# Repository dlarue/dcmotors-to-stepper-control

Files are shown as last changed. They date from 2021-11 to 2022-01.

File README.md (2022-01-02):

# dcmotors-to-stepper-control
This Arduino program is refered from: https://github.com/tuenhidiy/CNC-PLOTTER-FROM-DC-MOTORS-AND-OPTICAL-ENCODERS
Requires the L298N library by Andrea Lombardo found in the Arduino IDE Library Manager

It is used to control 2 DC motors having 2 optical encoders with step / direction signals typically found as stepper driver inputs on CNC machines.
In this project, DC motors can be simulated as same as stepper motors and we can control them via GRBL firmware for CNC application.
Combined with a GRBL based Arduino, a 3 axis CNC plotter/painter can be built from 2 DC motors w/encoders and a servo to operate as the Z axis.

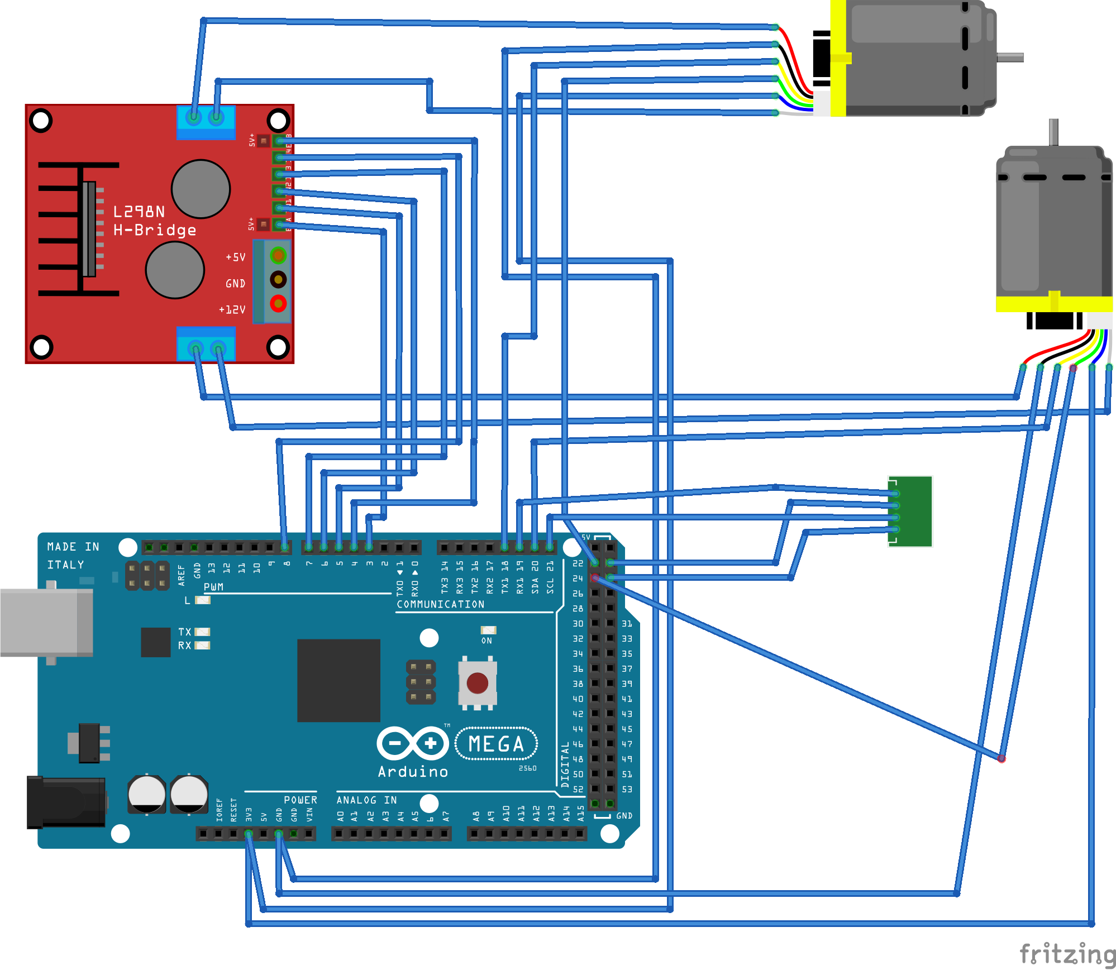
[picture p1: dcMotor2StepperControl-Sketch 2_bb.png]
Fritzing diagram


Inspired by this DIY wall painting bot with the hopes of having far more resolution capabilities and instead of using custom software for the workflow
be able to use commonly used CNC CAM software for GCode generation. 
https://niklasroy.com/graffomat/

Forked from this project in hopes it'll help other scale to bigger motors and higher accuracy:
https://www.instructables.com/3-AXIS-CNC-PLOTTER-FROM-DC-MOTORS-AND-OPTICAL-ENCO/

The firmware runs on an Arduino Mega 2560 as it uses 4 interrupts to handle step/direction input and encoder inputs.
The motors are driven by a L298N H-bridge contolling each channels via "ENA,IN1,IN2,IN3,IN4,ENB" inputs(outputs on the Arduino).
Motor encoder outputs are also connected directly to the Arduino Mega.

Arduino Pin	->	signal name

3		->	L298N-ENA

4		->	L298N-ENB

5		->	L298N-IN2

6		->	L298N-IN1

7		->	L298N-IN3

8		->	L298N-IN4

18		<-	MotorX-Encoder-chanA	(interrupt)

19		<-	MotorX-Step		(interrupt)

20		<-	MotorY-Encoder-chanA	(interrupt)

21		<-	MotorY-Step		(interrupt)

22		<-	MotorX-Encoder-chanB

23		<-	MotorX-Direction

24		<-	MotorY-Encoder-chanB

25		<-	MotorY-Direction

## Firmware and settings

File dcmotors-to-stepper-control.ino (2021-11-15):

/* 
 * This Arduino program is refered from: https://github.com/cswiger/dcservodrive by cswiger.
 * In this project, DC motors can be simulated as same as stepper motors and we can control them via GRBL firmware for CNC application.  
 */
   
// Timer2 library
#include "FlexiTimer2.h"

// PID library
#include <PID_v1.h>

// L298N library
// For two motors instance at once
#include <L298NX2.h>

// Quadrature Encoder Library
#include "Encoder.h"

// Pin definition
const unsigned int EN_A = 3;
const unsigned int IN1_A = 6;
const unsigned int IN2_A = 5;
//
const unsigned int IN1_B = 8;
const unsigned int IN2_B = 7;
const unsigned int EN_B = 4;

// Create the motor driver instance
// With Enable pin to control speed
//                     motor A            motor B
//            |------------------||------------------|
L298NX2 motors(EN_A, IN1_A, IN2_A, EN_B, IN1_B, IN2_B);

// Set up pins for the quadrature encoders - Arduino MEGA2560 has 6 interrupt pins.
#define EncoderX_ChannelA   18  // Interrupt 5
#define EncoderX_ChannelB   22
#define EncoderY_ChannelA   20  // Interrupt 3
#define EncoderY_ChannelB   24

// Set up STEP & DIRECTION pins for X and Y axis
#define STEP_XPIN           19  // Interrupt 4
#define STEP_YPIN           21  // Interrupt 2
#define DIR_XPIN            23
#define DIR_YPIN            25

// Turn on/ off debugging for X/Y motor
#define DEBUG_X             0
#define DEBUG_Y             0

// For calculating the actual movements
#define DEADBW_X          2.5 //4.5     // Deadband width = 4.5 --> Acceptable error for positioning in mm: 0.18mm.
#define DEADBW_Y          2.5 //4.5 //19.2    // Deadband width = 19.2 --> Acceptable error for positioning in mm: 0.1mm.

// for reference and only used in DEBUG output, Steps/mm must be set in GRBL config $100,$101
#define STEPSPERMM_X      24.5    // STEP/mm is used in the GRBL for DC motor X axis.
#define STEPSPERMM_Y      24.5 //192.0   // STEP/mm is used in the GRBL for DC motor Y axis.


// Set up Input
double INPUT_X;
double INPUT_Y;

double OLD_INPUT_X = 0;
double OLD_INPUT_Y = 0;

// Set up Actual value
double ACTUAL_X_MM;
double ACTUAL_Y_MM;

double OLD_ACTUAL_X_MM;
double OLD_ACTUAL_Y_MM;


// PID controller constants
double KP_X = 20.0;     // P for X motor
double KI_X = 0.03;     // I for X motor
double KD_X = 0.01;     // D for X motor

double KP_Y = 20.0; //9.0;      // P for Y motor
double KI_Y = 0.03; //0.02;     // I for Y motor
double KD_Y = 0.01;     // D for Y motor

// The Output variable motor speed to the motor driver
double OUTPUT_X;
double OUTPUT_Y;

double OLD_OUTPUT_X = 0;
double OLD_OUTPUT_Y = 0;

// Setpoint
double SETPOINT_X = 0;
double SETPOINT_Y = 0;

double OLD_SETPOINT_X = 0;
double OLD_SETPOINT_Y = 0;

double ERROR_X = 0;
double ERROR_Y = 0;

// PID controller
PID myPID_X(&INPUT_X, &OUTPUT_X, &SETPOINT_X, KP_X, KI_X, KD_X, DIRECT);
PID myPID_Y(&INPUT_Y, &OUTPUT_Y, &SETPOINT_Y, KP_Y, KI_Y, KD_Y, DIRECT);

// Setup optical encoders
Encoder XEncoder(EncoderX_ChannelA, EncoderX_ChannelB);
Encoder YEncoder(EncoderY_ChannelA, EncoderY_ChannelB);

void setup()
{
  // For debugging
  //Serial.begin(115200);

  pinMode(STEP_XPIN, INPUT);
  pinMode(STEP_YPIN, INPUT);
  pinMode(DIR_XPIN, INPUT);
  pinMode(DIR_YPIN, INPUT);  

  // The stepper simulator
  attachInterrupt(4, doXstep, RISING);  // PIN 19 (Interrupt 4) - Interrupt X step at rising edge pulses
  attachInterrupt(2, doYstep, RISING);  // PIN 21 (Interrupt 2) - Interrupt Y step at rising edge pulses
  
  // Outpout PWM limits
  myPID_X.SetOutputLimits(-255,255);
  myPID_Y.SetOutputLimits(-255,255);
  
  // Compute output every 1ms
  myPID_X.SetSampleTime(1);
  myPID_Y.SetSampleTime(1);
  
  // Setup PID mode
  myPID_X.SetMode(AUTOMATIC);
  myPID_Y.SetMode(AUTOMATIC);
  
  // Apply PID every 1ms by FlexiTimer2
  FlexiTimer2::set(1, 1.0/1000, doPID);
  FlexiTimer2::start();

  motors.setSpeedA(120);
  motors.setSpeedB(120);
  
}

void loop()
{
  // Read X and Y axis optical encoders
  INPUT_X = XEncoder.read();
  INPUT_Y = YEncoder.read();
  
  // Calculating the error
  ERROR_X = (INPUT_X - SETPOINT_X);
  ERROR_Y = (INPUT_Y - SETPOINT_Y);
  
  // For debugging
 if (DEBUG_X)
 {
  ACTUAL_X_MM = INPUT_X / STEPSPERMM_X;
 // Debugging X motor actual position in mm
 if (OLD_ACTUAL_X_MM != ACTUAL_X_MM)
 {
    Serial.print("ACTUAL X(MM): ");
    Serial.println(ACTUAL_X_MM);    
    OLD_ACTUAL_X_MM = ACTUAL_X_MM;
  }  
 // Debugging position X encoders
 if (OLD_INPUT_X != INPUT_X)
 {
    Serial.print("POSITION X: ");
    Serial.println(INPUT_X);    
    OLD_INPUT_X = INPUT_X;
  }
  // Debugging X stepping input
  if ( SETPOINT_X != OLD_SETPOINT_X )
  {
    Serial.print("SETPOINT X: ");
    Serial.println(SETPOINT_X);    
    OLD_SETPOINT_X = SETPOINT_X;
  }
  // Debugging X motor PWM output
  if ( OUTPUT_X != OLD_OUTPUT_X )
  {
    Serial.print("OUTPUT X: ");
    Serial.println(OUTPUT_X);    
    OLD_OUTPUT_X = OUTPUT_X;
  }
  
 }
 if (DEBUG_Y)
 {
    ACTUAL_Y_MM = INPUT_Y / STEPSPERMM_Y;
 // Debugging Y motor actual position in mm
 if (OLD_ACTUAL_Y_MM != ACTUAL_Y_MM)
 {
    Serial.print("ACTUAL Y(MM): ");
    Serial.println(ACTUAL_Y_MM);    
    OLD_ACTUAL_Y_MM = ACTUAL_Y_MM;
  }      
  // Debugging Y stepping input
  if ( SETPOINT_Y != OLD_SETPOINT_Y )
  {
    Serial.print("SETPOINT Y: ");
    Serial.println(SETPOINT_Y);
    OLD_SETPOINT_Y = SETPOINT_Y;
  }
  // Debugging position Y encoders
  if (OLD_INPUT_Y != INPUT_Y)
  {
    Serial.print("POSITION Y: ");
    Serial.println(INPUT_Y);
    OLD_INPUT_Y = INPUT_Y;
  }
  // Debugging Y motor PWM output
  if ( OUTPUT_Y != OLD_OUTPUT_Y )
  {
    Serial.print("OUTPUT Y: ");
    Serial.println(OUTPUT_Y);    
    OLD_OUTPUT_Y = OUTPUT_Y;
  }
  
 }
}

void doXstep() 
{
  if ( digitalRead(DIR_XPIN) == HIGH ) SETPOINT_X--;
  else SETPOINT_X++;
}

void doYstep()
{
  if ( digitalRead(DIR_YPIN) == HIGH ) SETPOINT_Y--;
  else SETPOINT_Y++;
}

void doPID() 
{
  interrupts();
  myPID_X.Compute();
  myPID_Y.Compute();
  if (abs(ERROR_X) < DEADBW_X) // If the motor X is in position within the deadband width (acceptable error)
    {
      // Turn off the X motor
      motors.setSpeedA(0);
    }
  else
    {
      // X Motor is regulated by PID controller ouput
      motors.setSpeedA(abs(int(OUTPUT_X)));
    }
  if (abs(ERROR_Y) < DEADBW_Y) // If the motor Y is in position within the deadband width (acceptable error)
    {
      // Turn off the Y motor
      motors.setSpeedB(0);
    }
  else
    {  
      // Y Motor is regulated by PID controller ouput
      motors.setSpeedB(abs(int(OUTPUT_Y)));
    }
  L298N::Direction directionX;
  L298N::Direction directionY;
  
  if(OUTPUT_X > 0)
    {
      directionX = L298N::FORWARD;
    }
  if(OUTPUT_X < 0)
    {
      directionX = L298N::BACKWARD;
    }
    
  if(OUTPUT_Y > 0)
    {
      directionY = L298N::FORWARD;
    }
  if(OUTPUT_Y < 0)
    {
      directionY = L298N::BACKWARD;
    }
  
  motors.runA(directionX);
  motors.runB(directionY);
}

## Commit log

2021-11-03 fixed pin connection labels
2021-11-04 moved PWM ENB from pin 9 to pin 4
2021-11-05 added Fritzing image and source file
    [dcMotor2StepperControl-Sketch 2.fzz]
2021-11-15 Add files via upload
    corrected defined 'direction' type
    [dcmotors-to-stepper-control.ino]
